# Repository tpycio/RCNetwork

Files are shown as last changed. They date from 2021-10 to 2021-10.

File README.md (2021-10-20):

# Network Controller Designed For RC2014

This is a COM20020-based network controller board designed for the RC2014 microcomputer system. The module has been prepared for operation in the CP/Net local area network.

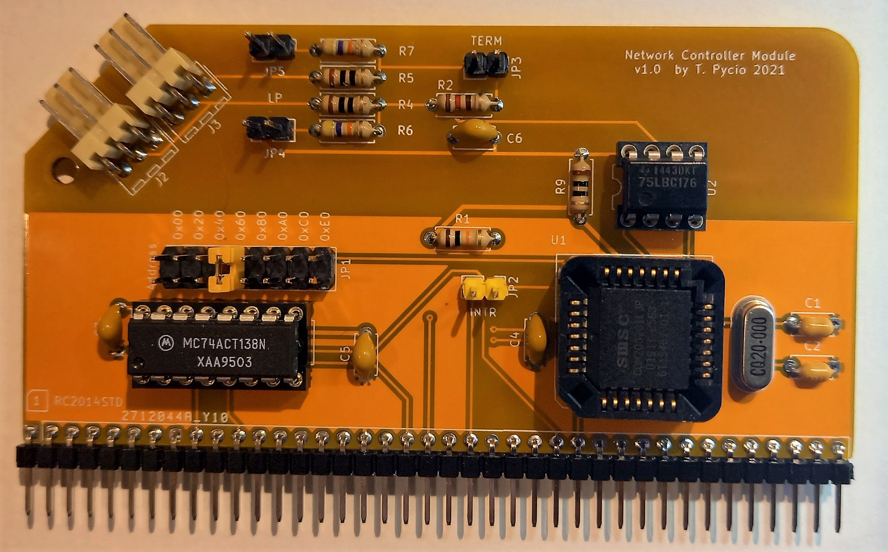
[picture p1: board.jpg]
populated board


## Bill of Materials

Component type     | Reference  | Description                                  | Quantity |
------------------ | ---------- | -------------------------------------------- | -------- |
PCB                |            | Network Controller PCB - Version 1.1         | 1        |
Integrated Circuit | U1         | COM20020ILJP - Arcnet Controller,28 pin PLCC | 1        |
Integrated Circuit | U2         | SN75176 -  Bus Transceiver, 8 pin DIP        | 1        |
Integrated Circuit | U3         | 74HCT138 - 3-to-8 line decoder, 16 pin DIP   | 1        |
Crystal            | Q1         | 20 MHz, Crystal Oscillator, HC-49S           | 1        |
Diode TVS          | D1 - D3    | SD05C , SOT323                               | 3        |
Pin Header         | J1         | 40 pin header, 2.54 mm pitch, angle          | 1        |
Connector Contacts | J2, J3     | 3 pin header, WF-03R 2.54 mm pitch, angle    | 1        |
Capacitor          | C1, C2     | 27 pF, ceramic, 5 mm pitch                   | 2        |
Capacitor          | C3 - C6    | 0.1 uF, 50V, MLCC, 5 mm pitch                | 4        |
Resistor           | R1         | 10 kohm, 0.25 W, axial                       | 1        |
Resistor           | R2         | 120 ohm, 0.25 W, axial                       | 1        |
Resistor           | R3, R4, R7 | 10 ohm, 0.25 W, axial                        | 3        |
Resistor           | R5, R5     | 47 kohm, 0.25 W, axial                       | 2        |
IC Socket          | U1         | 28 pin PLCC, through hole                    | 1        |
IC Socket          | U2         | 8 pin DIP                                    | 1        |
IC Socket          | U5         | 16 pin DIP                                   | 1        |
Jumper             | JP1        | Shunt, 2x8 pin 2.54 mm pitch                 | 1        |
Jumper             | JP2        | Shunt, 3 pin 2.54 mm pitch                   | 1        |
Jumper             | JP3 - JP5  | Shunt, 2 pin 2.54 mm pitch                   | 3        |

## License

Copyright 2021 Tadeusz Pycio

This work is licensed under a [Creative Commons Attribution-ShareAlike 4.0 International License](http://creativecommons.org/licenses/by-sa/4.0/).

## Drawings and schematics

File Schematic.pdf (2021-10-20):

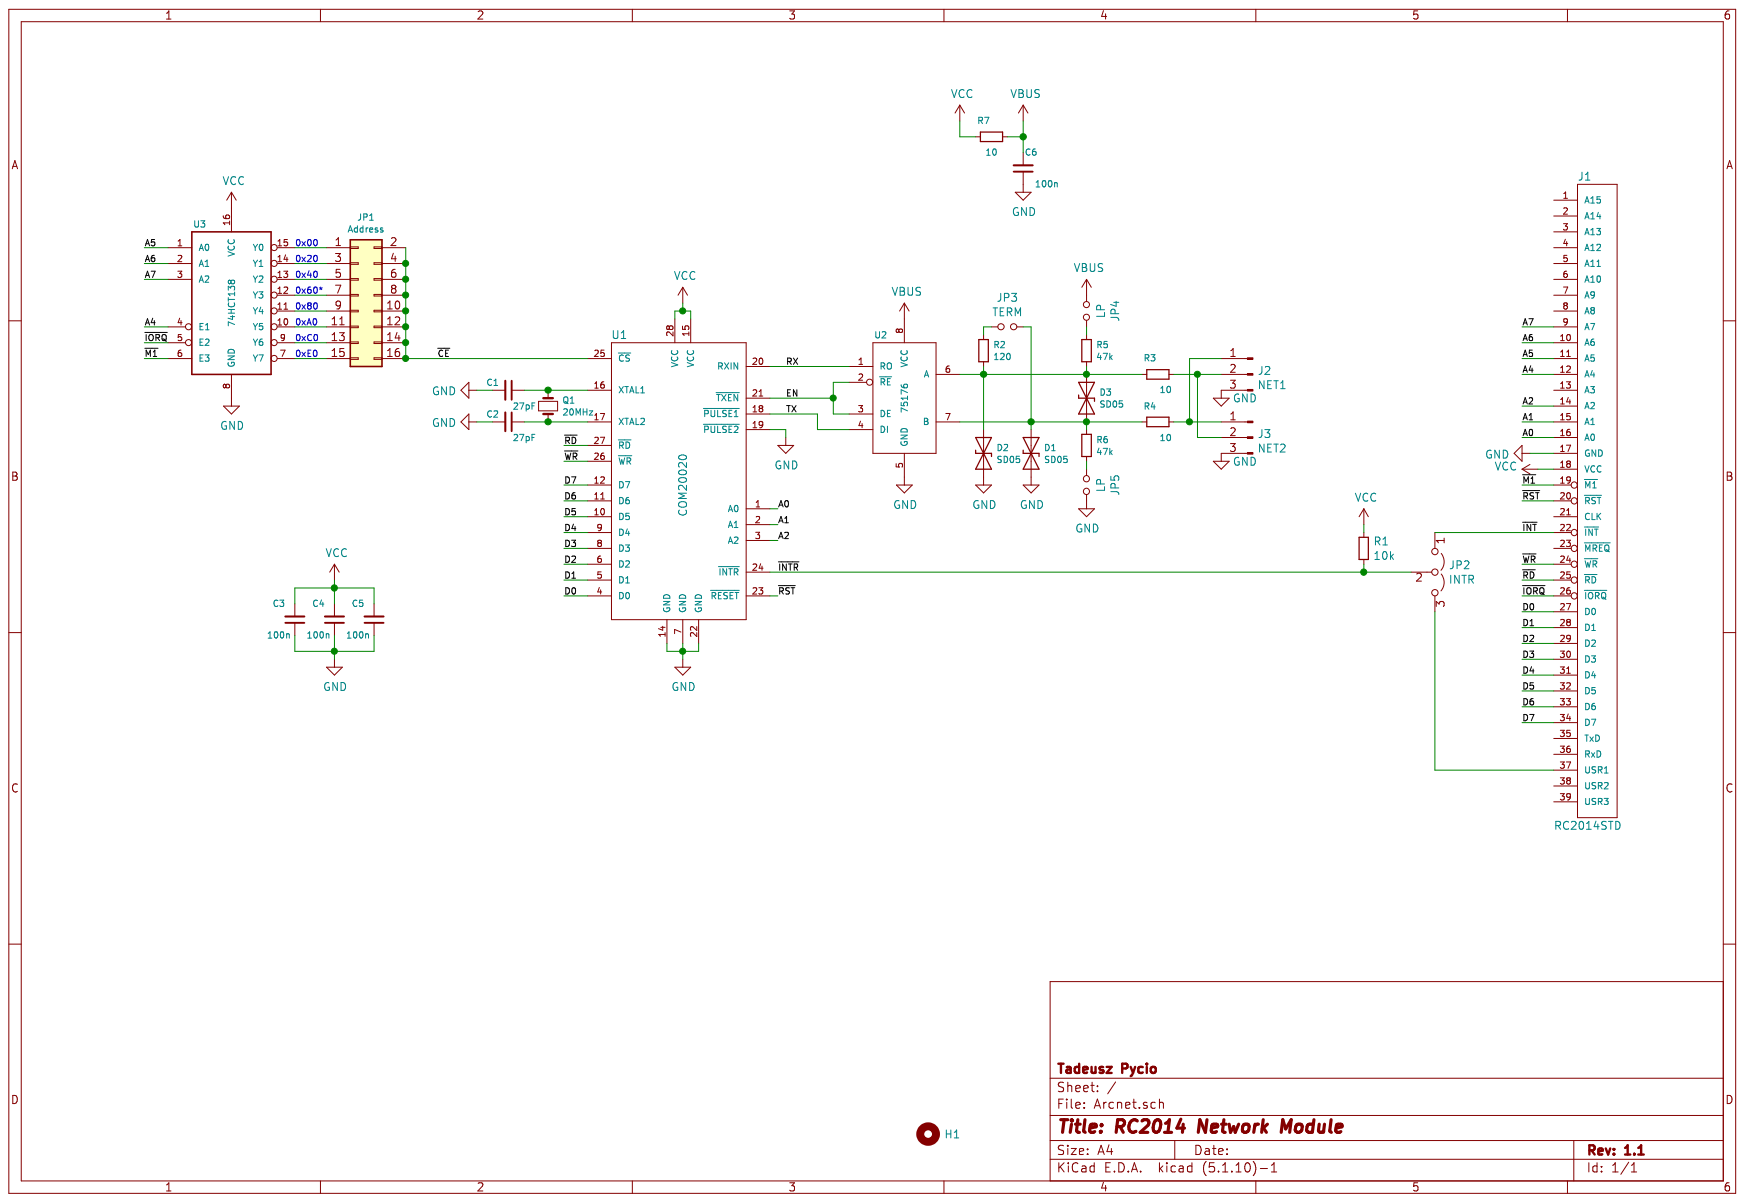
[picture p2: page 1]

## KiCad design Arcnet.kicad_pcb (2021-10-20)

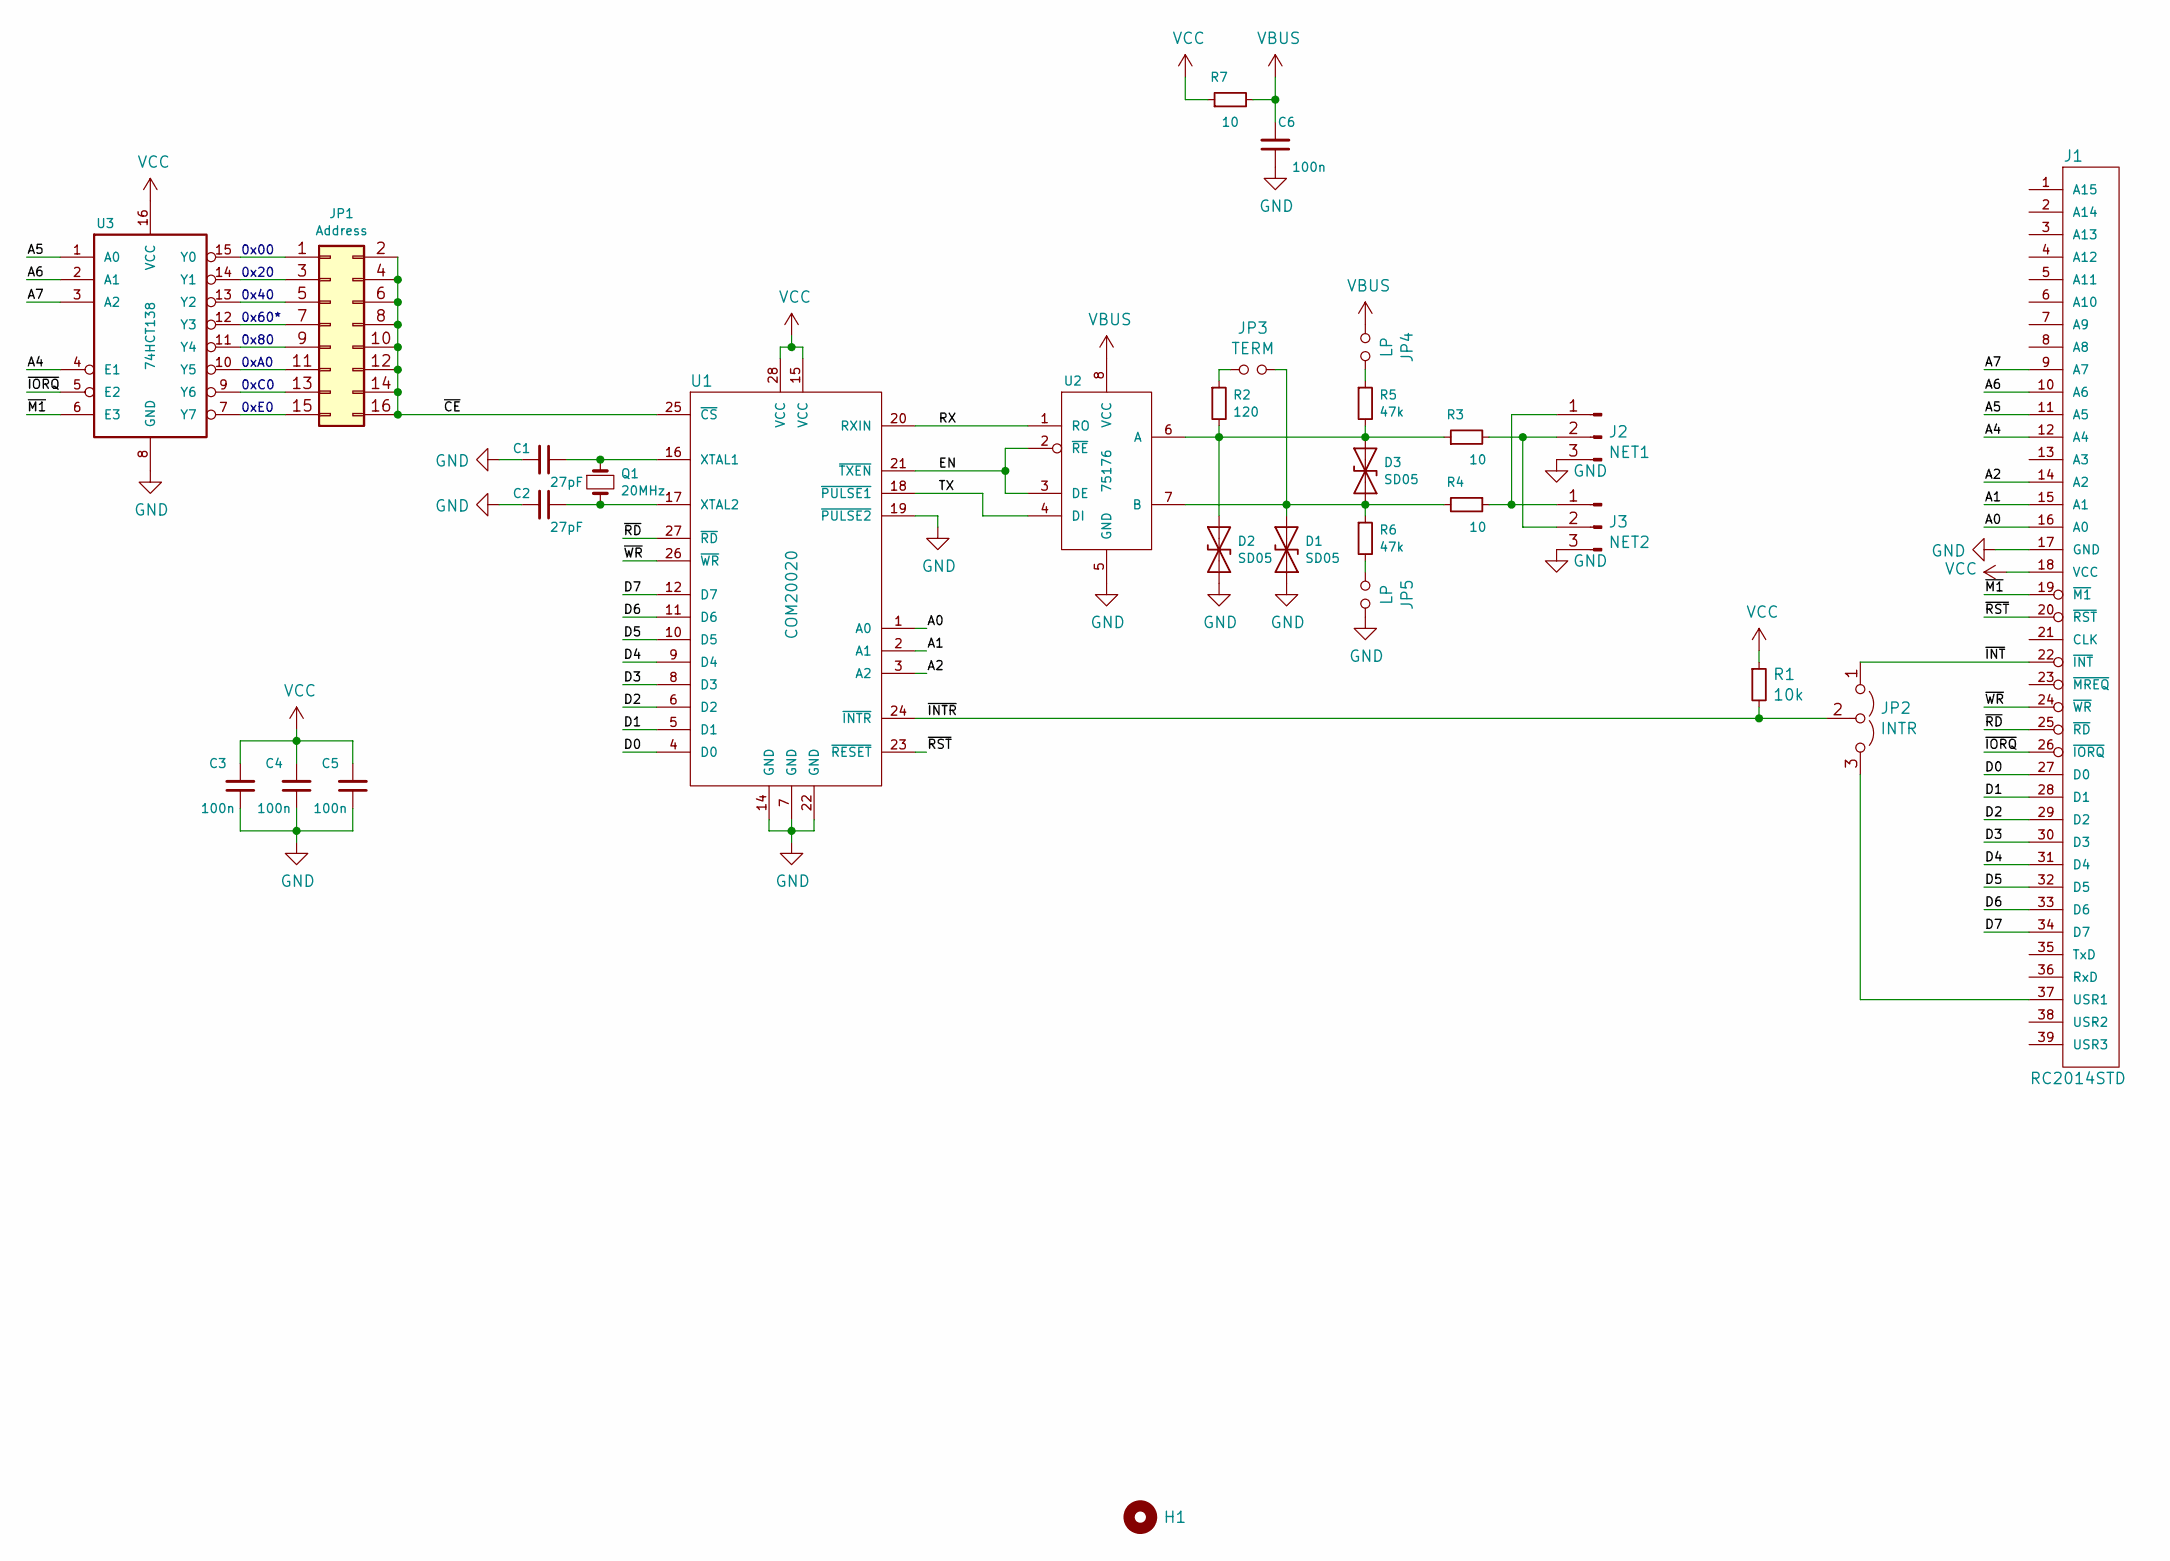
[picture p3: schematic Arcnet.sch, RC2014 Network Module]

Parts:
C1, C2: 27pF; C_Disc_D4.7mm_W2.5mm_P5.00mm
C3, C4, C5, C6: 100n; C_Disc_D4.7mm_W2.5mm_P5.00mm
D1, D2, D3: SD05; D_SOD-323_HandSolder
H1: MountingHole; MountingHole_3.2mm_M3_DIN965
J1: RC2014STD; PinHeader_1x39_P2.54mm_Vertical
J2: NET1; Molex_KK-254_AE-6410-03A_1x03_P2.54mm_Vertical
J3: NET2; Molex_KK-254_AE-6410-03A_1x03_P2.54mm_Vertical
JP1: Address; PinHeader_2x08_P2.54mm_Vertical
JP2: INTR; PinHeader_1x03_P2.54mm_Vertical
JP3: TERM; PinHeader_1x02_P2.54mm_Vertical
JP4, JP5: LP; PinHeader_1x02_P2.54mm_Vertical
Q1: 20MHz; Crystal_HC49-4H_Vertical
R1: 10k; R_Axial_DIN0207_L6.3mm_D2.5mm_P7.62mm_Horizontal
R2: 120; R_Axial_DIN0207_L6.3mm_D2.5mm_P7.62mm_Horizontal
R3, R4, R7: 10; R_Axial_DIN0207_L6.3mm_D2.5mm_P7.62mm_Horizontal
R5, R6: 47k; R_Axial_DIN0207_L6.3mm_D2.5mm_P7.62mm_Horizontal
U1: COM20020; PLCC-28_THT-Socket
U2: 75176; DIP-8_W7.62mm
U3: 74HCT138; DIP-16_W7.62mm

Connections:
/A0: J1.16 (A0), U1.1 (A0)
/A1: J1.15 (A1), U1.2 (A1)
/A2: J1.14 (A2), U1.3 (A2)
/A4: J1.12 (A4), U3.4 (E1)
/A5: J1.11 (A5), U3.1 (A0)
/A6: J1.10 (A6), U3.2 (A1)
/A7: J1.9 (A7), U3.3 (A2)
/D0: J1.27 (D0), U1.4 (D0)
/D1: J1.28 (D1), U1.5 (D1)
/D2: J1.29 (D2), U1.6 (D2)
/D3: J1.30 (D3), U1.8 (D3)
/D4: J1.31 (D4), U1.9 (D4)
/D5: J1.32 (D5), U1.10 (D5)
/D6: J1.33 (D6), U1.11 (D6)
/D7: J1.34 (D7), U1.12 (D7)
/EN: U1.21 (~TXEN), U2.2 (~RE), U2.3 (DE)
/RX: U1.20 (RXIN), U2.1 (RO)
/TX: U1.18 (~PULSE1), U2.4 (DI)
/~CE: JP1.2, JP1.4, JP1.6, JP1.8, JP1.10, JP1.12, JP1.14, JP1.16, U1.25 (~CS)
/~INT: J1.22 (~INT), JP2.1 (A)
/~INTR: JP2.2 (C), R1.2, U1.24 (~INTR)
/~IORQ: J1.26 (~IORQ), U3.5 (E2)
/~M1: J1.19 (~M1), U3.6 (E3)
/~RD: J1.25 (~RD), U1.27 (~RD)
/~RST: J1.20 (~RST), U1.23 (~RESET)
/~WR: J1.24 (~WR), U1.26 (~WR)
GND: C1.2, C2.2, C3.1, C4.1, C5.1, C6.1, D1.2 (A2), D2.2 (A2), J1.17 (GND), J2.3, J3.3, JP5.2, U1.7 (GND), U1.14 (GND), U1.19 (~PULSE2), U1.22 (GND), U2.5 (GND), U3.8 (GND)
unnamed: C1.1, Q1.1, U1.16 (XTAL1)
unnamed: C2.1, Q1.2, U1.17 (XTAL2)
unnamed: D1.1 (A1), D3.2 (A2), JP3.2, R4.2, R6.1, U2.7 (B)
unnamed: D2.1 (A1), D3.1 (A1), R2.2, R3.1, R5.2, U2.6 (A)
unnamed: J1.37 (USR1), JP2.3 (B)
unnamed: J2.1, J3.1, R4.1
unnamed: J2.2, J3.2, R3.2
unnamed: JP1.1, U3.15 (Y0)
unnamed: JP1.3, U3.14 (Y1)
unnamed: JP1.5, U3.13 (Y2)
unnamed: JP1.7, U3.12 (Y3)
unnamed: JP1.9, U3.11 (Y4)
unnamed: JP1.11, U3.10 (Y5)
unnamed: JP1.13, U3.9 (Y6)
unnamed: JP1.15, U3.7 (Y7)
unnamed: JP3.1, R2.1
unnamed: JP4.2, R5.1
unnamed: JP5.1, R6.2
VBUS: C6.2, JP4.1, R7.2, U2.8 (VCC)
VCC: C3.2, C4.2, C5.2, J1.18 (VCC), R1.1, R7.1, U1.15 (VCC), U1.28 (VCC), U3.16 (VCC)

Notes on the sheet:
0x00
0x20
0x40
0x60*
0x80
0xA0
0xC0
0xE0

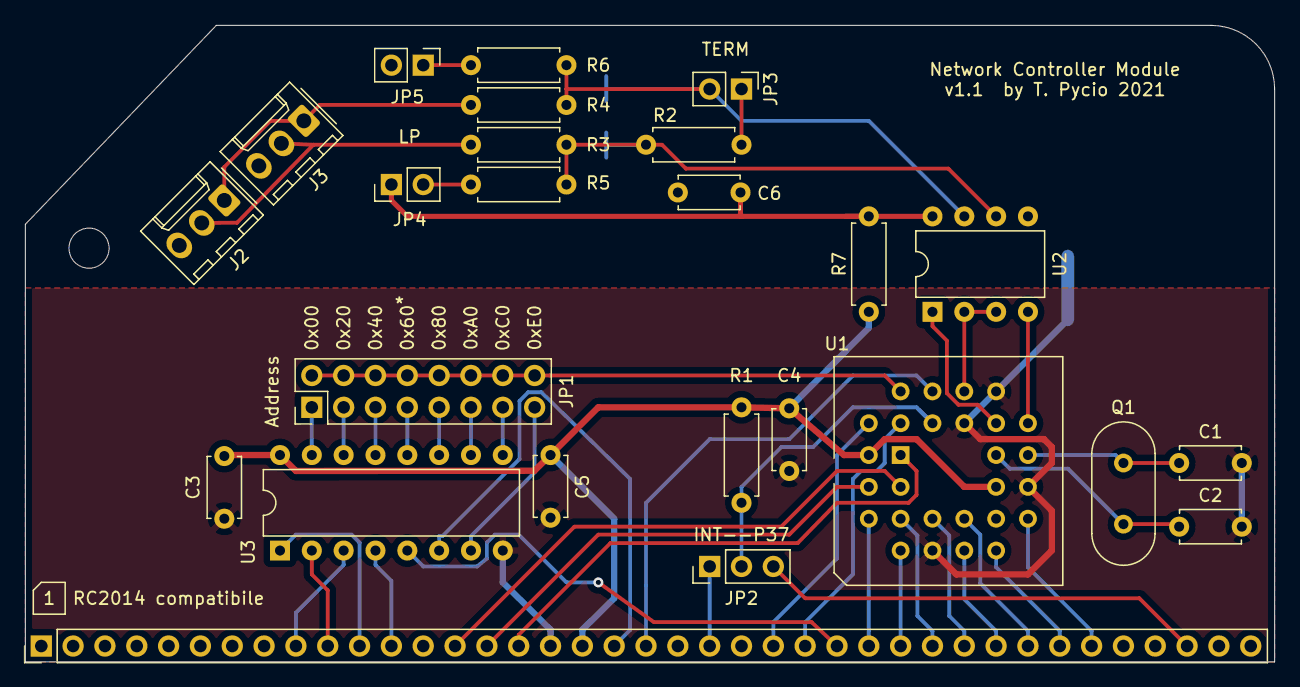
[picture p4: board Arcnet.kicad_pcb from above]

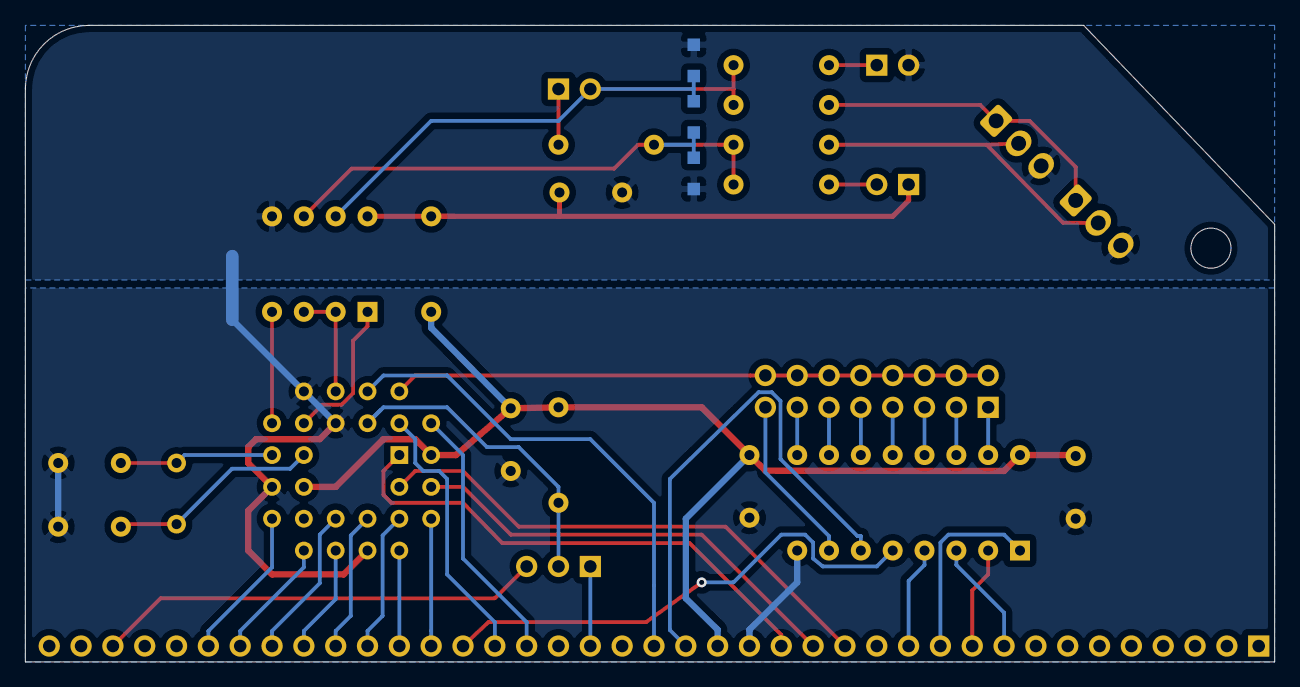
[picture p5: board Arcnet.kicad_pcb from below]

Board: 2 copper layers, 99.7 x 50.8 mm, 29 parts (3 on the bottom side), 47 nets.
